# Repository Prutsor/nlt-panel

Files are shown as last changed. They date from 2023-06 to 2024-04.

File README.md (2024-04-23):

# NLT Panel

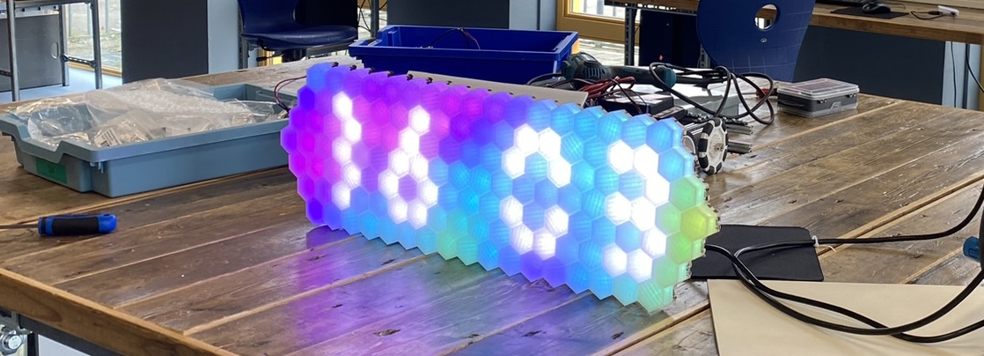
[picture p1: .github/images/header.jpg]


> Wij hebben voor de NLT-module "Arduino" een neopixel klok ontworpen. Met de 3D-printer hebben we hexagons gemaakt die we in een lasergesneden houten frame hebben geklikt. Op het frame zitten led-strips bevestigd die door een ESP8266 worden aangestuurd. Hierop zit zelfgemaakte software, geschreven in C++, om de juiste tijd weer te geven. Door een programma, geschreven in Rust, kunnen instellingen van de klokmodule getest worden op een 3D-model via een videostream. Hierdoor zijn er eindeloze mogelijkheden voor toekomstige weergaven op het display, zoals tekst, weereffecten en camera streams. Meer informatie over de klok is te vinden op: `https://www.prutsor.nl/nlt/panel`

## Benodigdheden

### Materialen

* [1,2 kg doorzichtig filament](https://www.prusa3d.com/product/clear-pla-filament-1kg/)
* Houten plaat van 25x70 cm
* LED-voeding van 5V (minimaal 6A)
* LED-strip van 5m (30 LED/m)
* ESP8266 NodeMCU V2

### Gereedschappen

* Lasersnijmachine
* 3D-printer

## Instructies

### Stap 1: Print de hexagons

1. Download het bestand ["print_hexagons.stl"](.github/files/print_hexagons.stl).
2. Print het bestand vijf keer.
3. Terwijl de hexagons aan het printen zijn, kun je doorgaan met de volgende stappen.

<details>
    <summary>Optioneel: zijstukjes om de LED-kanalen te dichten</summary>

1. Download het bestand ["print_caps.stl"](.github/files/print_caps.stl).
2. Print het bestand één keer.
3. Klik de stukjes aan de zijkant van de hexagons op het bord.

<p align="center">
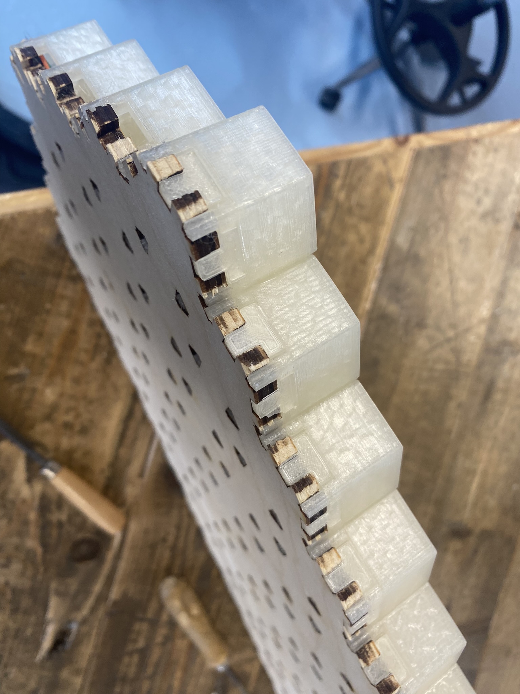
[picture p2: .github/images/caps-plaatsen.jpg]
Plaatsen van de zijstukjes
    
</p>

</details>

### Stap 2: Lasersnij de houten plaat

1. Download het bestand ["backplate.svg"](.github/files/backplate.svg).
2. Open het bestand in je lasersnijprogramma.
3. Laat het lasersnijprogramma de houten plaat snijden.

### Stap 3: Bevestig de LED-strips

1. Knip de LED-strip in vijf delen: 2x17, 2x18, 2x19 en 1x20 LED's.
2. Plaats de LED-strips op de houten plaat volgens de richtingen in de afbeelding hieronder.

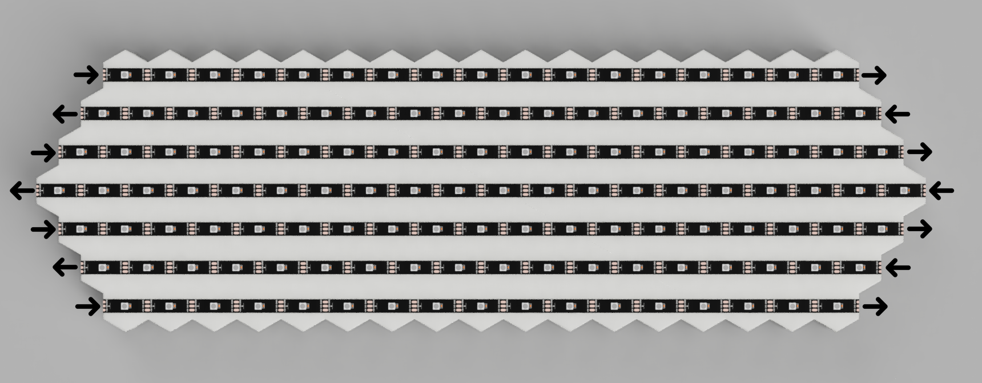
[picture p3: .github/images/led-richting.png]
Richting van de LED-strips


3. Solder de LED-strips aan elkaar.

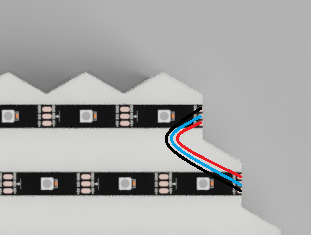
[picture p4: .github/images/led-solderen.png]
Solderen van de LED-strips


### Stap 4: Plaats de hexagons

1. Plaats de hexagons op de houten plaat, bovenop de LED-strips.
2. Schuur de pootjes van de hexagons indien nodig.

Plaatsen van de hexagons

### Stap 5: Houten standaard lasersnijden

1. Download het bestand ["mount_plate.svg"](.github/files/mount_plate.svg)
2. Open het bestand in je lasersnijprogramma
3. Laat het lasersnijprogramma de houten plaat snijden.
4. Download het bestand ["print_caps_secondary.stl"](.github/files/print_caps_secondary.stl).
5. Print het bestand één keer.
6. Zet het in elkaar zoals hieronder aangegeven.

Plaatsen van de standaard en bijbehorende caps

### Stap 6: Firmware uploaden

Om de firmware op de ESP te zetten moet je eerst de volgende dingen hebben:
 * [Visual Studio Code](https://code.visualstudio.com/)
 * [PlatformIO](https://platformio.org/install/ide?install=vscode)

Na het installeren van deze programma’s moet je de repository downloaden en de `firmware` map openen in Visual Studio Code. Als je de map hebt geopend, moet je naar de `include` map gaan en het `config.example.h` bestand kopiëren naar `config.h`. In dit bestand moet je de wifi gegevens invullen. Hierbij is `ssid` de naam van het netwerk en `password` het wachtwoord van het netwerk. Verder kun je de naam van de klok eventueel aanpassen door `SERVICE_NAME` te wijzigen. Nu moet je de ESP aansluiten en op de `upload` knop klikken (hieronder aangegeven)

<p align="center">
    
</p>

Je kunt de klok via de visualizer testen voordat je alle elektronica aansluit om te kijken of het gelukt is. De visualizer is [hier](https://github.com/Prutsor/nlt-panel-4/releases) te downloaden. Om met de klok te verbinden moet je op het verbind icoontje klikken. Daar zou je de klok moeten zien verschijnen. 

> Let op: je moet op hetzelfde WiFi-netwerk zitten als de klok om ermee te verbinden

### Stap 7: Voeg de elektronica toe

Maak de voeding en ESP vast op de plaat van de standaard. Gebruik voor de ESP eventueel een breadboard of iets dergelijks.

<p align="center">
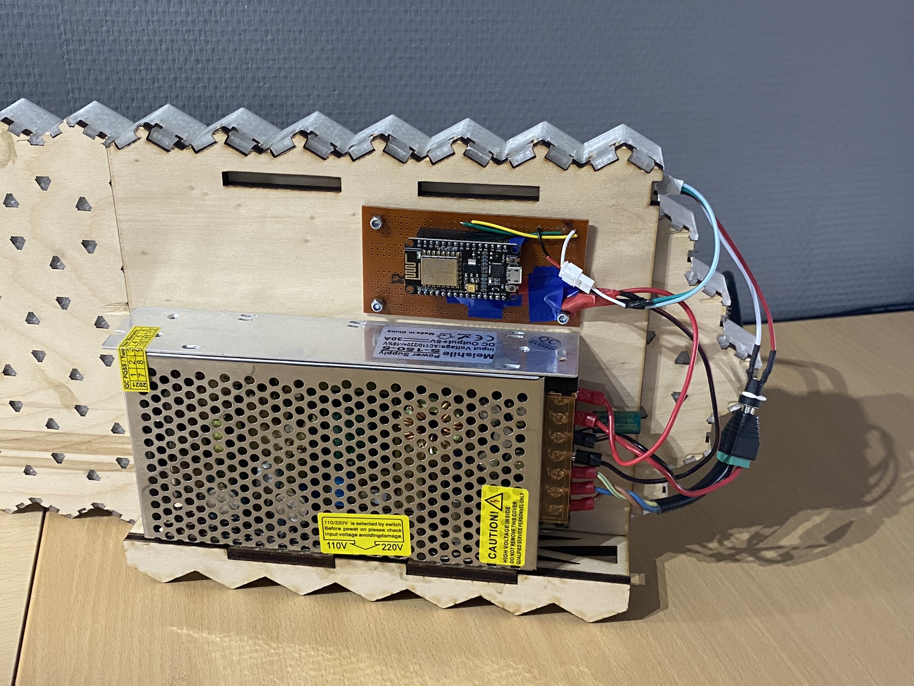
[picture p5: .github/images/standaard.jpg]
Plaatsen van de voeding en ESP
    
</p>

Verbind de voeding met de ESP en de ledstrip. Gebruik een kabel om de positieve en negatieve polen van de voeding te verbinden met de respectievelijke polen van de ESP en de LED-strip. Gebruik een kabel om de pin 6 van de ESP te verbinden met de data pin van de LED-strip.

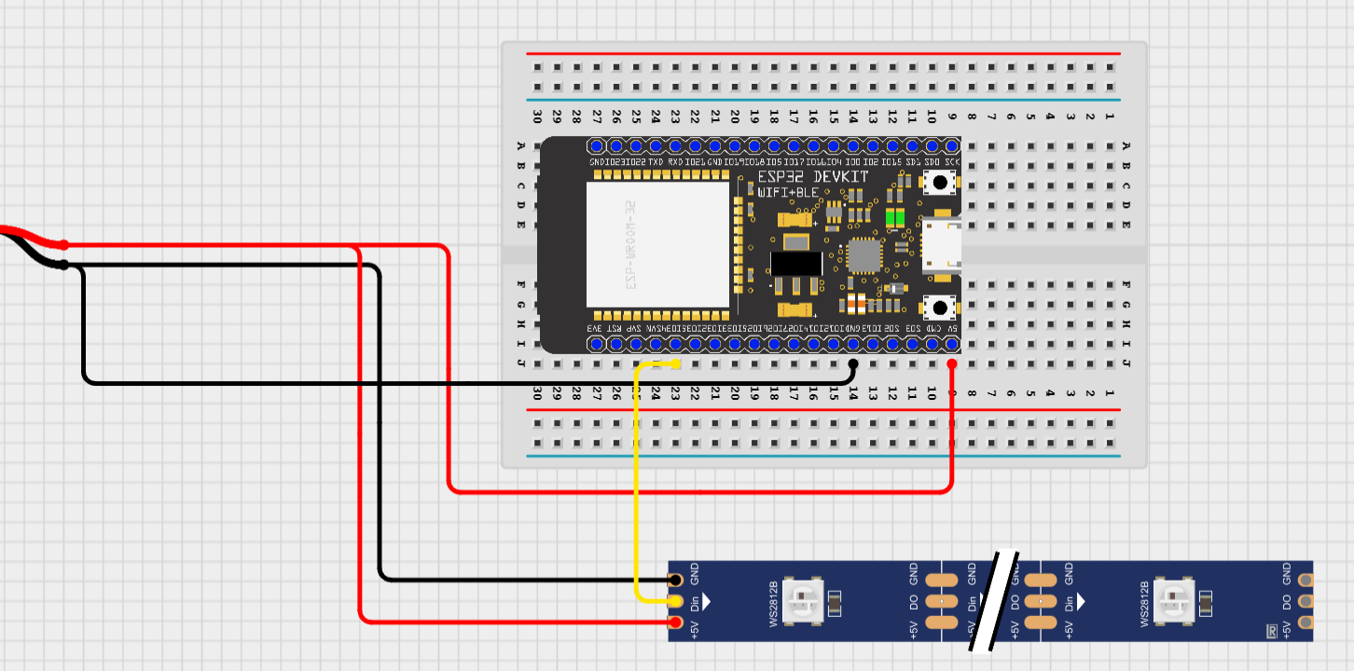
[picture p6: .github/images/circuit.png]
Aansluiten van de elektronica


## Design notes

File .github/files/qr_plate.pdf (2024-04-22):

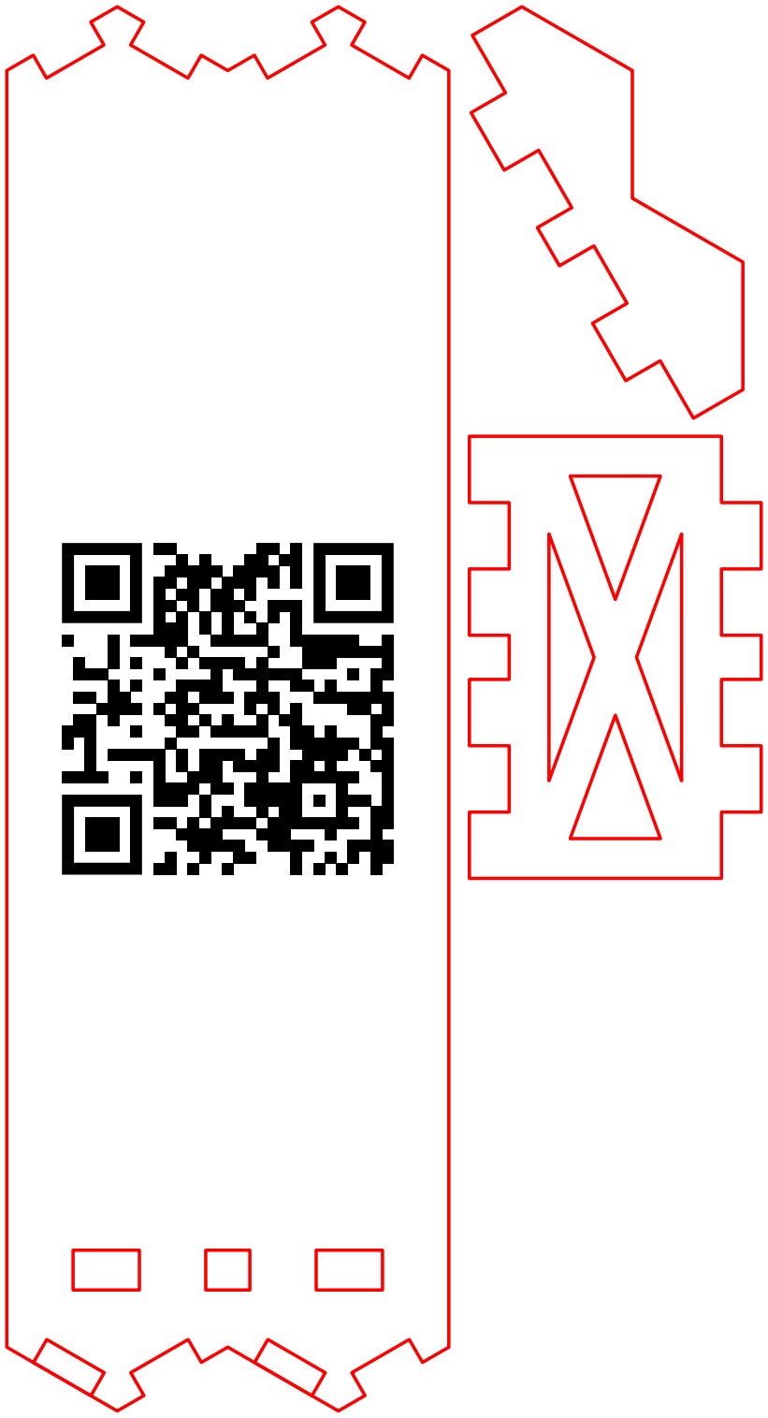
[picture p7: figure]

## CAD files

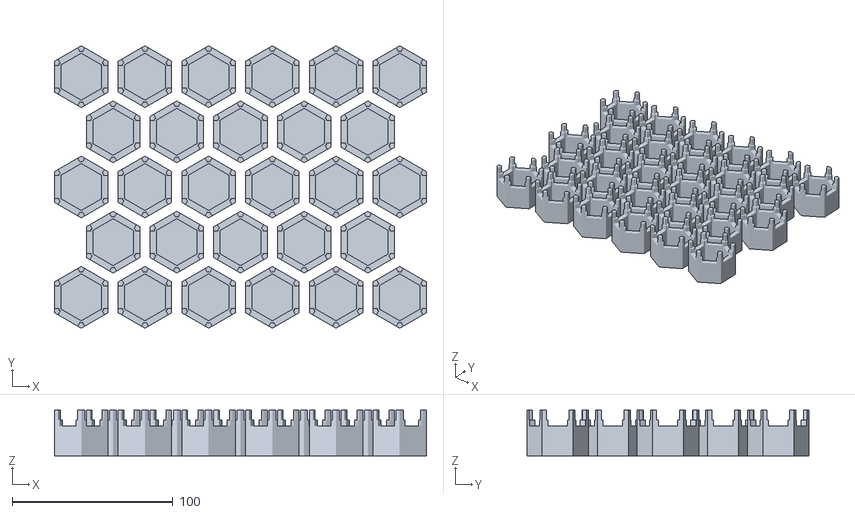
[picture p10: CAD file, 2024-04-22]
.github/files/print_hexagons.stl
231.7 x 175.9 x 28.5

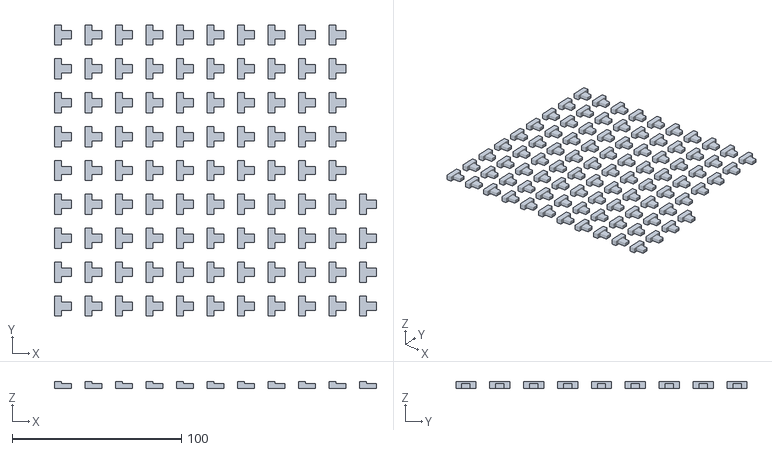
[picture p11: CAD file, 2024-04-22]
.github/files/print_caps.stl
190.0 x 172.0 x 4.00

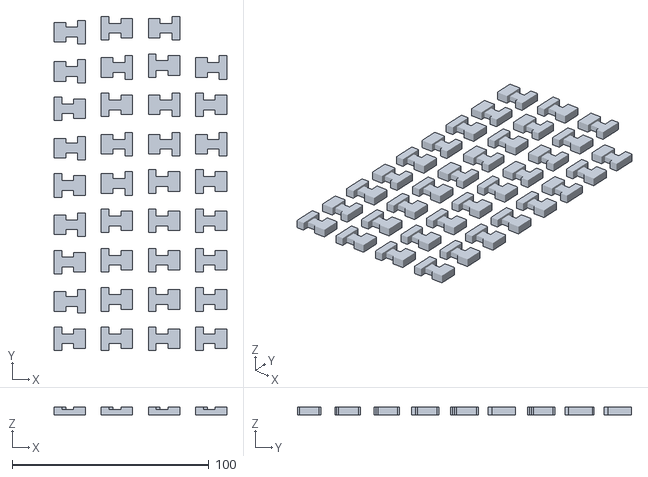
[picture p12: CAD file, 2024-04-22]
.github/files/print_caps_secondary.stl
88.0 x 170.0 x 4.00

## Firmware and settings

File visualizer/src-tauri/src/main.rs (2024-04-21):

#![cfg_attr(not(debug_assertions), windows_subsystem = "windows")]

use std::{net::Ipv4Addr, sync::Arc};

use serde::{Deserialize, Serialize};
use tauri::{EventHandler, Manager};
use tokio::io;

#[cfg(target_os = "windows")]
use window_vibrancy::apply_mica;

use mdns_sd::{ServiceDaemon, ServiceEvent};
use tokio::io::{AsyncReadExt, AsyncWriteExt};
use tokio::net::TcpStream;
use tokio::sync::{mpsc, Mutex};

#[derive(Clone, Serialize, Deserialize)]
pub struct Panel {
    pub name: String,
    pub version: Option<String>,

    pub ip: Option<Ipv4Addr>,
    pub port: u16,
}

#[derive(Default)]
struct AppState {
    panels: Vec<Panel>,

    is_streaming: bool,
}

#[tauri::command]
async fn get_panels(state: tauri::State<'_, Arc<Mutex<AppState>>>) -> Result<Vec<Panel>, String> {
    let state = state.lock().await;
    Ok(state.panels.clone())
}

#[tauri::command]
async fn add_panel(
    state: tauri::State<'_, Arc<Mutex<AppState>>>,
    panel: Panel,
) -> Result<(), String> {
    let mut state = state.lock().await;
    state.panels.push(panel.clone());
    Ok(())
}

#[derive(Debug)]
enum Command {
    Data,
    Disconnect,
}

#[tauri::command]
async fn panel_start_stream(
    window: tauri::Window,
    state: tauri::State<'_, Arc<Mutex<AppState>>>,
    panel: Panel,
) -> Result<(), String> {
    if state.lock().await.is_streaming {
        return Err("Already streaming".to_string());
    }

    state.lock().await.is_streaming = true;

    let mut socket = match TcpStream::connect((panel.ip.unwrap().to_string(), 1935)).await {
        Ok(socket) => socket,
        Err(e) => {
            eprintln!("Failed to connect to panel: {}", e);
            return Err(e.to_string());
        }
    };

    let (tx, mut rx) = mpsc::channel(1);
    let data_sender = tx.clone();
    let stop_sender = tx.clone();

    let data_event = window.listen("stream_data", move |event| {
        data_sender.try_send((Command::Data, event)).unwrap();
    });

    let stop_event = window.listen("stream_stop", move |event| {
        stop_sender.try_send((Command::Disconnect, event)).unwrap();
    });

    let mut buf = vec![0; 1024];

    loop {
        tokio::select! {
            result = socket.read(&mut buf) => {
                match result {
                    Ok(n) => {
                        buf.truncate(n);

                        match buf[0] {
                            0x01 => {
                                if buf.len() > 255 {
                                    window.emit("stream_data", buf.clone()).unwrap();
                                }
                            }
                            0x02 => {
                                window.emit("stream_metadata", buf.clone()).unwrap();
                            }
                            _ => {
                                eprintln!("Unknown packet type: {}", buf[0]);
                            }
                        }
                    }
                    Err(ref e) if e.kind() == io::ErrorKind::WouldBlock => {
                        continue;
                    }
                    Err(e) => {
                        eprintln!("Failed to read from TCP stream: {}", e);
                        break;
                    }
                }
            }

            payload = rx.recv() => {
                match payload {
                    Some((Command::Data, event)) => {
                        let data = serde_json::from_str::<Vec<u8>>(&event.payload().unwrap()).unwrap();

                        socket.write(&data).await.expect("Failed to send data");
                    }
                    Some((Command::Disconnect, _)) => {
                        break;
                    }
                    None => {
                        return Ok(());
                    }
                }
            }
        }

        buf = vec![0; 1024];
    }

    window.unlisten(data_event);
    window.unlisten(stop_event);

    state.lock().await.is_streaming = false;

    Ok(())
}

#[tauri::command]
async fn panel_is_streaming(state: tauri::State<'_, Arc<Mutex<AppState>>>) -> Result<bool, String> {
    Ok(state.lock().await.is_streaming)
}

fn main() {
    let empty_state: Arc<Mutex<AppState>> = Arc::new(Mutex::new(AppState::default()));

    tauri::Builder::default()
        .manage(empty_state)
        .invoke_handler(tauri::generate_handler![
            get_panels,
            add_panel,
            panel_start_stream,
            panel_is_streaming
        ])
        .setup(|app| {
            let window = app.get_window("main").unwrap();

            #[cfg(target_os = "windows")]
            let _ = apply_mica(&window, Some(true)); // TODO: check for dark mode

            window.set_decorations(true).unwrap();
            window.show().unwrap();

            tauri::async_runtime::spawn(async move {
                std::thread::sleep(std::time::Duration::from_secs(2)); //TODO: wait for page load

                let mdns = ServiceDaemon::new().expect("Failed to create daemon");
                let receiver = mdns
                    .browse("_nlt-panel._tcp.local.")
                    .expect("Failed to browse");

                while let Ok(event) = receiver.recv() {
                    match event {
                        ServiceEvent::ServiceResolved(info) => {
                            println!(
								"At: Resolved a new service: {} host: {} port: {} IP: {:?} TXT properties: {:?}",
								info.get_fullname(),
								info.get_hostname(),
								info.get_port(),
								info.get_addresses(),
								info.get_properties(),
							);

                            let panel = Panel {
                                name: info.get_hostname().split('.').next().unwrap().to_string(),
                                version: info
                                    .get_properties()
                                    .get("version")
                                    .and_then(|value| Some(value.val_str().to_string())),
                                ip: Some(
                                    info.get_addresses_v4()
                                        .iter()
                                        .next()
                                        .unwrap()
                                        .to_owned()
                                        .clone(),
                                ),
                                port: info.get_port(),
                            };

                            window.emit("panel_discovered", &panel).unwrap();
                        }
                        _other_event => {}
                    }
                }
            });

            Ok(())
        })
        .run(tauri::generate_context!())
        .expect("error while running tauri application");
}

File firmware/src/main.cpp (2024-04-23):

#include <config.h>

#include <Arduino.h>
#include <ArduinoOTA.h>

#include <ESP8266HTTPClient.h>
#include <ESP8266WiFi.h>
#include <ESP8266mDNS.h>

#include <logger.h>
#include <time.h>

#include "config.h"
#include "constants.hpp"
#include "font.hpp"

#include <Adafruit_NeoPixel.h>

#include "Display.h"
#include "Visualizer.h"

#include "settings.hpp"

DISPLAY_MODE s_display_mode = DISPLAY_MODE::Time;
BACKGROUND_MODE s_background_mode = BACKGROUND_MODE::Noise;

char s_display_text[128] = "test";
uint32_t s_background_color = 0x039dfc;

// @version 4.1.0

constexpr uint8_t MAJOR = 4;
constexpr uint8_t MINOR = 1;
constexpr uint8_t PATCH = 1;

Adafruit_NeoPixel strip(STRIP_LEDS, STRIP_PIN, STRIP_TYPE);

Display display(strip);
Visualizer visualizer(display);

logging::Logger logger;

time_t now;
struct tm tm;

void setup()
{
	Serial.begin(115200);

	const unsigned long start = millis();

	logger.log(logging::LoggerLevel::LOGGER_LEVEL_INFO, "WIFI", "Setting up WiFi (SSID: %s)", ssid);

	WiFi.begin(ssid, password);

	logger.log(logging::LoggerLevel::LOGGER_LEVEL_INFO, "DISPLAY", "Setting up display");

	display.setup();

	logger.log(logging::LoggerLevel::LOGGER_LEVEL_INFO, "WIFI", "Waiting for WiFi connection");

	while (WiFi.status() != WL_CONNECTED)
	{
		delay(100);
	}

	logger.log(logging::LoggerLevel::LOGGER_LEVEL_INFO, "WIFI", "Connected, IP address: %s", WiFi.localIP().toString().c_str());

	logger.log(logging::LoggerLevel::LOGGER_LEVEL_INFO, "MDNS", "Setting up MDNS (Service name: %s)", SERVICE_NAME);

	if (!MDNS.begin(SERVICE_NAME))
	{
		logger.log(logging::LoggerLevel::LOGGER_LEVEL_ERROR, "MDNS", "Error setting up MDNS responder!");
	}

	MDNS.addService("nlt-panel", "tcp", SERVICE_PORT);
	MDNS.addServiceTxt("nlt-panel", "tcp", "version", (String)MAJOR + "." + (String)MINOR + "." + (String)PATCH);

	logger.log(logging::LoggerLevel::LOGGER_LEVEL_INFO, "NTP", "Setting up NTP (Server: %s, TZ: %s)", NTP_SERVER, NTP_TZ);
	configTime(NTP_TZ, NTP_SERVER);

	logger.log(logging::LoggerLevel::LOGGER_LEVEL_INFO, "VISUALIZER", "Setting up visualizer (Port: %d)", VISUALIZER_PORT);
	visualizer.setup();

	logger.log(logging::LoggerLevel::LOGGER_LEVEL_INFO, "OTA", "Setting up OTA");
	ArduinoOTA.begin(false);

	logger.log(logging::LoggerLevel::LOGGER_LEVEL_INFO, "SETUP", "Done! Took %d ms", millis() - start);
}

void loop()
{
	MDNS.update();
	ArduinoOTA.handle();

	time(&now);
	localtime_r(&now, &tm);

	display.render_background();
	
	if (s_display_mode == DISPLAY_MODE::Time)
	{
		display.render_time(tm.tm_hour, tm.tm_min, tm.tm_sec);
	}
	else if (s_display_mode == DISPLAY_MODE::Text)
	{
		display.render_text(s_display_text);
	}

	display.update();
	visualizer.update();
}

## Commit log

2023-06-10 fix memory crash & switch from udp to tcp
    [main.cpp]
2023-10-25 fix: switch ci command
2023-10-26 fix: change ldf to chain+
2023-10-26 fix: re-enable the visualizer stream
    [main.cpp]
2023-10-28 fix: update display in setup_wifi
    [main.cpp]
2023-10-29 fix: change ci push path filter
2023-10-29 fix: windows 10 crashing
    [main.rs]
2023-10-29 fix: kill corrupted streams
    [main.rs]
2024-03-21 fix: allow unknown packet types
    [main.rs]
2024-03-27 fix (CI): decapitalize logger
    [main.cpp]
2024-03-27 fix (CI): use hpp
    [main.cpp]
2024-04-21 fix (visualizer): send data to socket
    [main.rs]
2024-04-22 feat: add readme
    [print_caps.stl, print_caps_secondary.stl, print_hexagons.stl]
2024-04-23 fix (visualizer): correctly set default material
